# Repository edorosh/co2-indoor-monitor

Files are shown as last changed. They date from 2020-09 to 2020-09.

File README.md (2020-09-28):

# CO2 Indoor Monitor (MH-Z19B)
A CO2 Monitor is a device that helps you understand the environmental Carbon Dioxide (CO2) levels in an office, room and  other indoor area.  

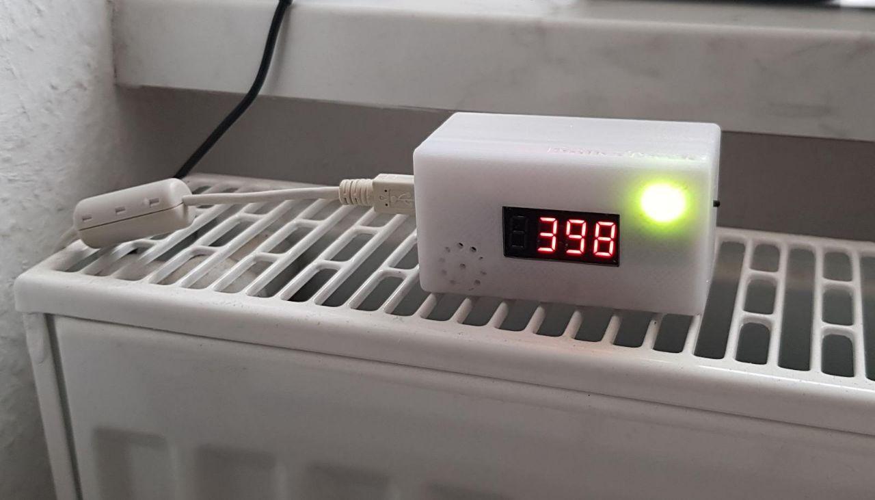
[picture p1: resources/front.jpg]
PROJECT_PHOTO


It first warns and then alarms in case of CO2 level reaches a nonacceptable level. It has 4 Digit 7-Segment Display Module, a LED illumination along with a Buzzer. Currently the device is powered by a USB source only.  

CO2 Levels are measured as PPM (Parts Per Million). The standard outdoor level is around 350ppm, and is the optimum level for freshness. However, it can get up to 600ppm indoor without any adverse affects. Once it gets past 600ppm people will start noticing adverse affects.

The LED is GREEN when CO2  < 700ppm. It switches to BLUE when the level is < 1200ppm and finally it changes to red for the higher levels and starts playing back a song.

# Circuit Schematic
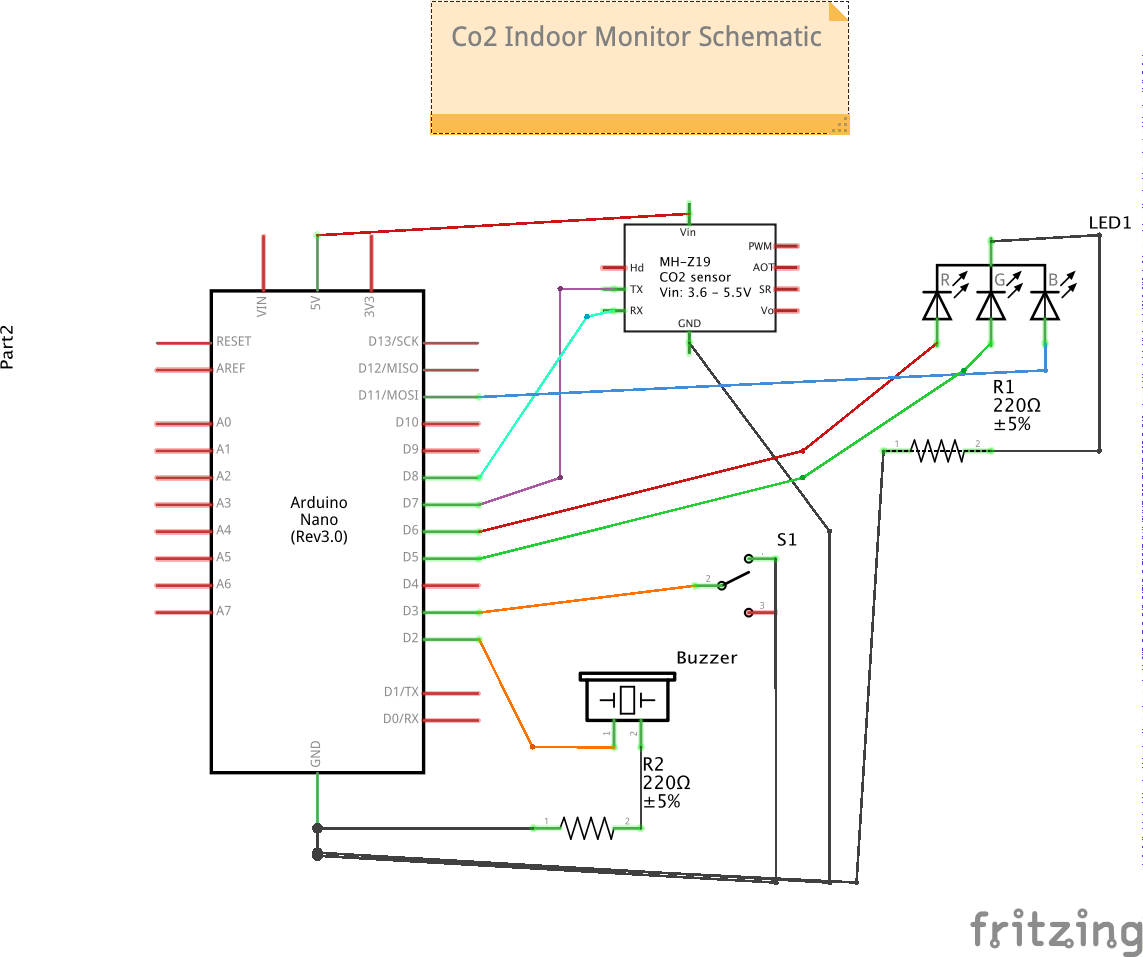
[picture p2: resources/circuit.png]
CIRCUIT_PHOTO


# Upload Firmware
New to Arduino? Check [this official HOWTO](https://www.arduino.cc/en/main/howto). Before uploading the sketch check if you have all requried libraries insalled. You may want to copy all of them inside `libraries` manually into %Home%/Arduino/libraries or install them all via "Manage Libraries" option.

# Project Structure

| Folder | Description |
| ---  | --- |
| `firmware`  | Arduino Firmware |
| `libraries` | All required libraries |
| `3d` | STL and Step files for the enclosure |
| `resources` | Resources for the README file |  

# List of used libraries
* [GyverButton](https://github.com/AlexGyver/GyverLibs/tree/master/GyverButton)
* [GyverTimer](https://github.com/AlexGyver/GyverLibs/tree/master/GyverTimer)
* [MH-Z19](https://github.com/WifWaf/MH-Z19)
* [TM1637](https://github.com/avishorp/TM1637)
* [Non Blocking rtttl](https://github.com/cefn/non-blocking-rtttl-arduino)

# Bill of Materials
* PCB Prototype Board 3x7cm
* Arduino Nano
* MH-Z19B
* Female PCB pins
* Passive Buzzer 5v (12mm)
* 2-way switch
* Connection wires
* RGB LED with common Cathode
* 4 digit 7 Segment Display TM1637
* 220 Ohm Resistor x2
* Hex Spacer 2M 6mm x2 with screws x2

# 3D Model
STL files for the enclosue are inside `3d` folder. Here you may find [Fusion 360 sources](https://a360.co/3mZy4vN).
I printed the parts with PETG material, 30% infill and 0.2mm layer height. PLA works worse and it easily breaks. The LED part is filled up by a Hot Glue.  The Display is fixed by a Hot Glue as well. THe PCB board is fixed by 2 Hex Spacers.

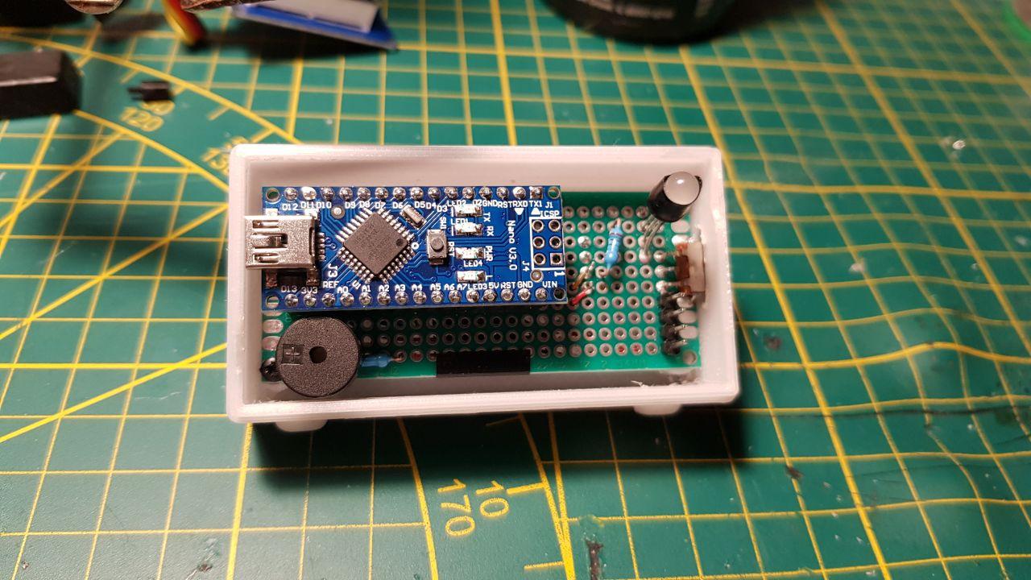
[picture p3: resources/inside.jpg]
INSIDE_PHOTO

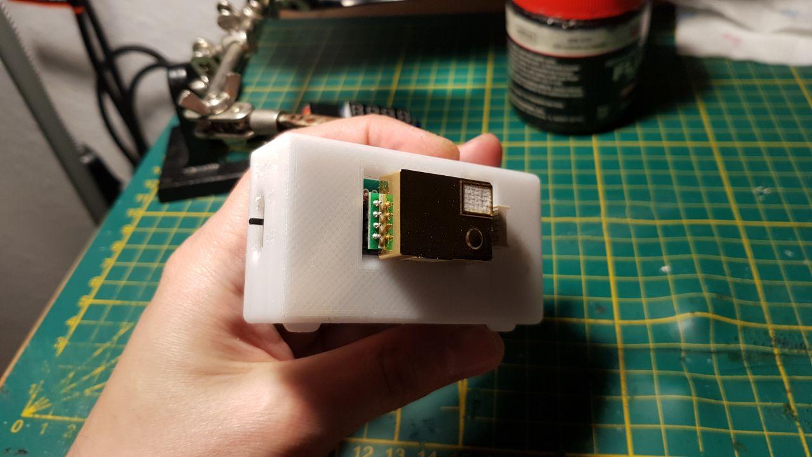
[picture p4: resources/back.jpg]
BACK_PHOTO


# License
MIT License. Not for a commercial usage.

# TODO
* think about using platform.io
* add settings description
* add feature: blikning red
* add feature: different PWN values per colour
* add feature: repeating the melody
* add feature: add battery support

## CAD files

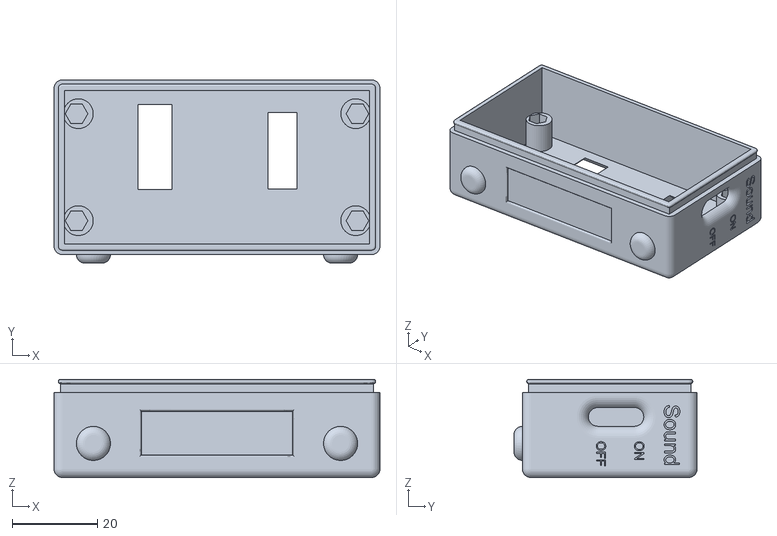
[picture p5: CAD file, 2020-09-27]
3d/Bottom.stl
76.5 x 43.0 x 23.0

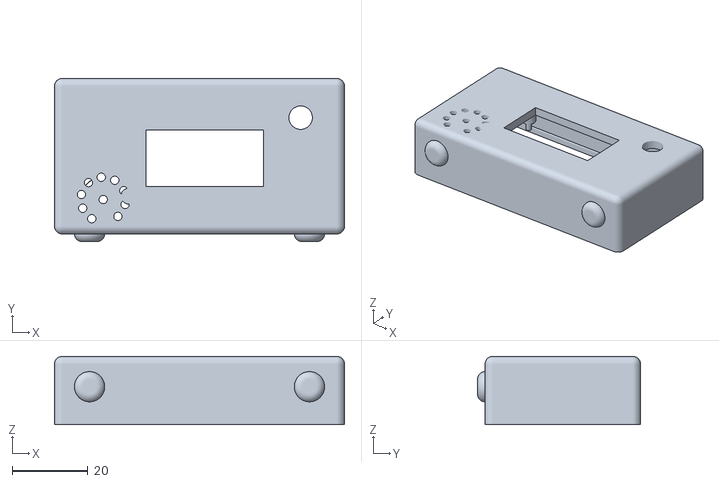
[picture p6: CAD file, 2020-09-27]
3d/Top.stl
76.5 x 43.0 x 18.0

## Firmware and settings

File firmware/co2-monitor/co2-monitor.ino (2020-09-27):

/**
 * CO2 Indoor Monitor (MH-Z19B)
 * 
 * Monitors CO2 level in a room. It first warns and then alarms in case of CO2 level reaches a nonacceptable 
 * level. It has 4 Digit 7-Segment Display Module, a LED illumination along with a Buzzer. 
 * Currently the device is powered by a USB source only.
 * 
 * Author: Evgeny Doros
 * Email: eugene.dorosh@gmail.com
 * Github: https://github.com/edorosh
 * License: MIT 
 * 
 * THE SOFTWARE IS PROVIDED "AS IS", WITHOUT WARRANTY OF ANY KIND, EXPRESS OR
 * IMPLIED, INCLUDING BUT NOT LIMITED TO THE WARRANTIES OF MERCHANTABILITY,
 * FITNESS FOR A PARTICULAR PURPOSE AND NONINFRINGEMENT. IN NO EVENT SHALL THE
 * AUTHORS OR COPYRIGHT HOLDERS BE LIABLE FOR ANY CLAIM, DAMAGES OR OTHER
 * LIABILITY, WHETHER IN AN ACTION OF CONTRACT, TORT OR OTHERWISE, ARISING FROM,
 * OUT OF OR IN CONNECTION WITH THE SOFTWARE OR THE USE OR OTHER DEALINGS IN THE
 * SOFTWARE.
 */
#include <SoftwareSerial.h>                                // Remove if using HardwareSerial or Arduino package without SoftwareSerial support
#include <MHZ19.h>
#include <TM1637Display.h>
#include <GyverTimer.h>
#include <GyverButton.h>
#include <rtttl.h>

#define RX_PIN 7                                          // Rx pin which the MHZ19 Tx pin is attached to
#define TX_PIN 8                                          // Tx pin which the MHZ19 Rx pin is attached to
#define BAUDRATE 9600                                     // Device to MH-Z19 Serial baudrate (should not be changed)

// Module connection pins (Digital Pins)
#define DISPLAY_CLK_PIN 10
#define DISPLAY_DIO_PIN 9

#define LED_RED_PIN 6
#define LED_GREEN_PIN 5
#define LED_BLUE_PIN 11
#define LED_BRIGHTNESS 60

#define BUZZER_PIN 2
#define BTN_MUTE_PIN 3
#define MELODY_REPEAT_INTERVAL_MS 5e3

#define CO2_READ_INTERVAL_MS 2e3                              // MH-Z19 read timeout

// Aha - Take on me
const char song_P[] PROGMEM = "TakeOnMe:d=4,o=4,b=160:8f#5,8f#5,8f#5,8d5,8p,8b,8p,8e5,8p,8e5,8p,8e5,8g#5,8g#5,8a5,8b5,8a5,8a5,8a5,8e5,8p,8d5,8p,8f#5,8p,8f#5,8p,8f#5,8e5,8e5,8f#5,8e5,8f#5,8f#5,8f#5,8d5,8p,8b,8p,8e5,8p,8e5,8p,8e5,8g#5,8g#5,8a5,8b5,8a5,8a5,8a5,8e5,8p,8d5,8p,8f#5,8p,8f#5,8p,8f#5,8e5,8e5";

MHZ19 myMHZ19;                                             // Constructor for library
SoftwareSerial mySerial(RX_PIN, TX_PIN);                   // (Uno example) create device to MH-Z19 serial
TM1637Display display(DISPLAY_CLK_PIN, DISPLAY_DIO_PIN);
GTimer_ms melodyRepeatTimeout;
ProgmemPlayer player(BUZZER_PIN);

GButton muteButton(BTN_MUTE_PIN, HIGH_PULL);

unsigned long getDataTimer = 0;
int CO2 = 0;
boolean muteMode = false;
boolean requestPlayMelody = false;
boolean requestResetMelody = false;
boolean melodyCompleted = false;
uint8_t data[] = { 0xff, 0xff, 0xff, 0xff };

enum LED_COLOR {LED_OFF, LED_RED, LED_GREEN, LED_BLUE, LED_YELLOW};

void setup() {
    Serial.begin(9600);                                     // Device to serial monitor feedback

    mySerial.begin(BAUDRATE);                               // (Uno example) device to MH-Z19 serial start   
    myMHZ19.begin(mySerial);                                // *Serial(Stream) refence must be passed to library begin(). 

    myMHZ19.autoCalibration(false);                              // Turn auto calibration ON (OFF autoCalibration(false))

    pinMode(LED_RED_PIN, OUTPUT);
    pinMode(LED_GREEN_PIN, OUTPUT);
    pinMode(LED_BLUE_PIN, OUTPUT);
    setLED(LED_OFF);

    //display.setBrightness(0x0f);
    display.setBrightness(5);

    player.setSong(song_P);
    //attachInterrupt(digitalPinToInterrupt(BTN_MUTE_PIN), isrMute, CHANGE);
}

//void isrMute() {
//  muteButton.tick();
//}

void loop() {
  muteButton.tick();
  //melodyTick();

  if (muteButton.isHold()) {
    if (!player.isSilent()) {
      requestResetMelody = true;
    }
    
    muteMode = true;
  } else {
    muteMode = false;
  }

  if (requestResetMelody) {
    player.initSong();
    requestResetMelody = false;
    Serial.println("Melody has been reset");
  }

  if (requestPlayMelody && !muteMode && !melodyCompleted) {
    melodyCompleted = !player.pollSong();

    if (melodyCompleted) {
      // skip next start in MS
    }
  } else if (requestPlayMelody && muteMode && !player.isSilent()) {
    player.silence();
  }

  if (millis() - getDataTimer >= CO2_READ_INTERVAL_MS)
  {
    CO2 = myMHZ19.getCO2(); // Request CO2 (as ppm)
    
    Serial.print("CO2 (ppm): ");                      
    Serial.println(CO2);
    
    handleLedIndicator();
    handleMusic();
  
    display.showNumberDec(CO2, false);
    
    getDataTimer = millis();
  }
}

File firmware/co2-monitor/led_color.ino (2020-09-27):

void setLED(LED_COLOR color) {
  // Turn all the colors
  analogWrite(LED_RED_PIN, 0);
  analogWrite(LED_GREEN_PIN, 0);
  analogWrite(LED_BLUE_PIN, 0);

  // Turn on the color
  switch (color) {
    case LED_RED:
      analogWrite(LED_RED_PIN, LED_BRIGHTNESS);
      break;
    case LED_GREEN: 
      analogWrite(LED_GREEN_PIN, LED_BRIGHTNESS);
      break;
    case LED_BLUE: 
      analogWrite(LED_BLUE_PIN, LED_BRIGHTNESS);
      break;
    case LED_YELLOW: 
      analogWrite(LED_RED_PIN, LED_BRIGHTNESS - 50); //todo: refactor by 100%
      analogWrite(LED_GREEN_PIN, LED_BRIGHTNESS);
      break;
  }
}
